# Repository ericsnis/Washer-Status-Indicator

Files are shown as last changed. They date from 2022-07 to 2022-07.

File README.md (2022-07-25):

# Washer Status Indicator
Washing Machine status indicator using ESP32

## Features

- Simple LED indicator for at a glance washing machine and clothes dryer status.
  - Green LED for "OFF / Ready"
  - Red LED for "ON/ In Use"
  - Could be used to indicate status of other things.
- Uses commonly available ESP32 NodeMCU boards or other boards with identical pinout.
  - Not the similarly named **_ESP8266_** NodeMCU boards, which uses different chip and pinout.
  - Tested with [Inland/Microcenter ESP32 board](https://www.microcenter.com/product/613822/inland-esp32-wroom-32d-module).
  - Designs using 1206 SMT or through hole components available.
- Open source hardware
- Software uses [PubSubClient](https://pubsubclient.knolleary.net/) to communicate with MQTT server
  - Uses [OpenHab](https://www.openhab.org/) home automation sever for source of MQTT data.
    - Requires MQTT server such as [Mosquitto](https://mosquitto.org/).
	  - [Basic directions](https://community.openhab.org/t/oh3-mqtt-setup-and-configuration) for Mosquitto and OpenHab
    - Follow directions for configuring [MQTT binding](https://www.openhab.org/addons/bindings/mqtt/).
  - Could be used with other MQTT sources like [Home Assistant](https://www.home-assistant.io/).

## Boards
The schematic folder contains the board and schematic files in Eagle format
- Designs for 1206 SMT LEDs and resistors or through hole components
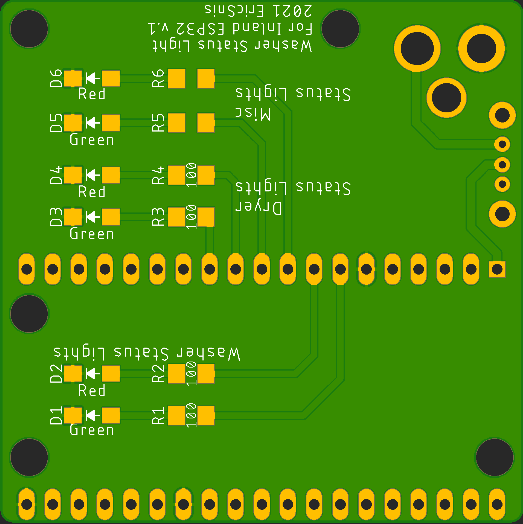
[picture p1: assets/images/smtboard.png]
MQTT washer thing


## Code
The code folder contains the program code to compile and upload to the ESP32
- Use [Platform.io](https://docs.platformio.org/en/latest/integration/ide/vscode.html) installed on [Visual Studio Code](https://code.visualstudio.com/) AKA: VSCode to compile and upload.
- Open the code folder in VSCode then compile, PlatformIO should download any dependencies.

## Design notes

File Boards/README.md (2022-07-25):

# Boards
 The schematic folder contains the board and schematic files in Eagle format

## Files for surface mount (SMT) boards
- _Washer Machine Status Inland ESP32 1206.brd_ - Surface mount board file
- _Washer Machine Status Inland ESP32 1206.sch_ - Surface mount schematic file

## Files for through hole component boards
- _Washer Machine Status Inland ESP32 Through Hole.brd_ - Through hole component board file
- _Washer Machine Status Inland ESP32 Through Hole.sch_ - Through hole component schematic file

**You need _both_ the .brd and .sch files to open the board in Eagle.**

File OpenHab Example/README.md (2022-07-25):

# MQTT Example for OpenHab
- [Basic directions](https://community.openhab.org/t/oh3-mqtt-setup-and-configuration) for Mosquitto and OpenHab
- See [OpenHab Things](https://www.openhab.org/docs/configuration/things.html) and [OpenHab Items](https://www.openhab.org/docs/configuration/items.html) for infomation on setting up items.
- Uses current sensor to monitor power consumed by the machines to determine their states.
  - TP-Link [KP125](https://www.kasasmart.com/us/products/smart-plugs/kasa-smart-plug-slim-energy-monitoring-kp125) or equivalent with energy monitoring.
  - Needs to have an binding available for OpenHab to monitor
    - [List](https://www.openhab.org/addons/) of available OpenHab bindings
	- [TP-Link binding](https://www.openhab.org/addons/bindings/tplinksmarthome/) for OpenHab, includes examples of things and items.
Provided as example with no guarantees express or implied.

## Rule Files
washer.rules
 - Washing machine rules to update status based on wattage used
 - Machine uses less than 2.5 watts when off, wattages exceeding this will be considered "on".
 - Updates WashingMachineStatus to publish update to MQTT topic
dryer.rules
 - Clothes dryer rules to update status based on wattage used
 
## OpenHab Things & Items
 - WashingMachine_Power item is linked to current power used thing on current sensor
 - WashingMachineStatus is item linked to the MQTT thing "washer"
   - Washer thing has channel called WasherStatus
   - WashingMachineStatus is linked to the WasherStatus channel
   - Updates sent to WashingMachineStatus gets published to MQTT topic sensors/washerstatus

**Images of my setup**
### MQTT broker binding
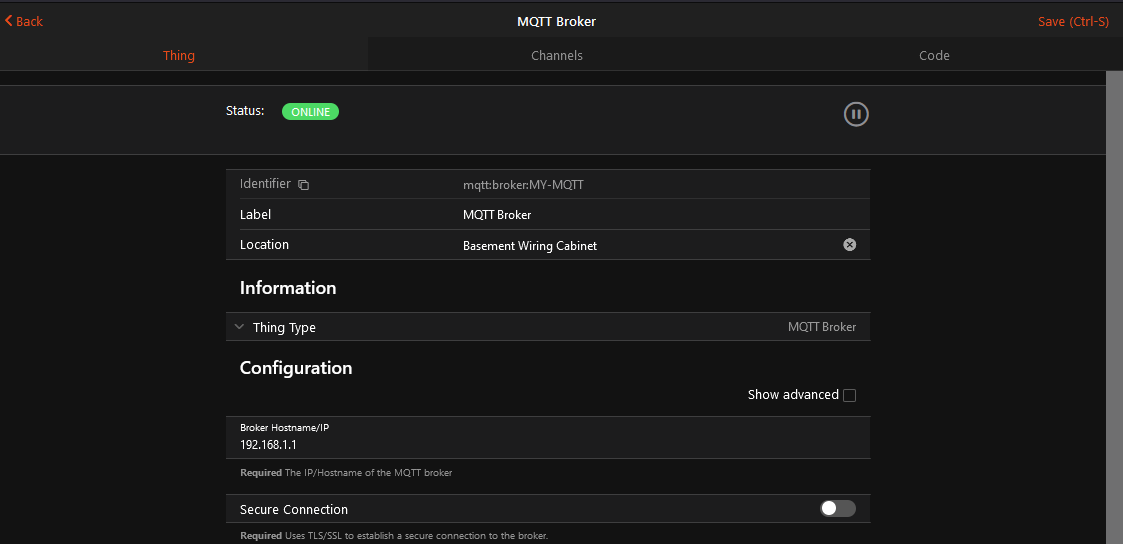
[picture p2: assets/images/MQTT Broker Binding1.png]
MQTT broker binding

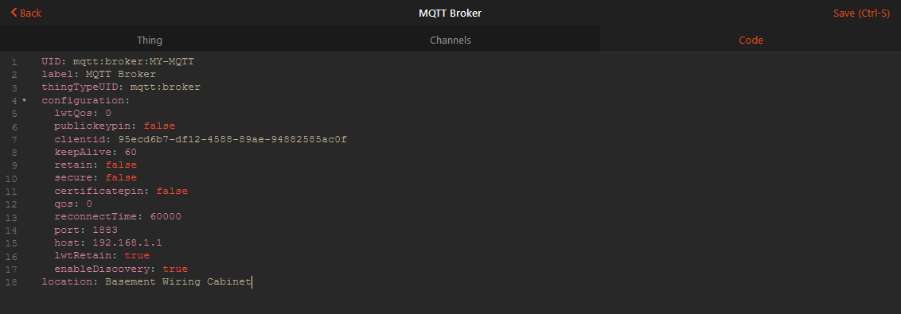
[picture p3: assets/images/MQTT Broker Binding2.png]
MQTT broker binding code


### MQTT washer thing
**Washer thing tab**
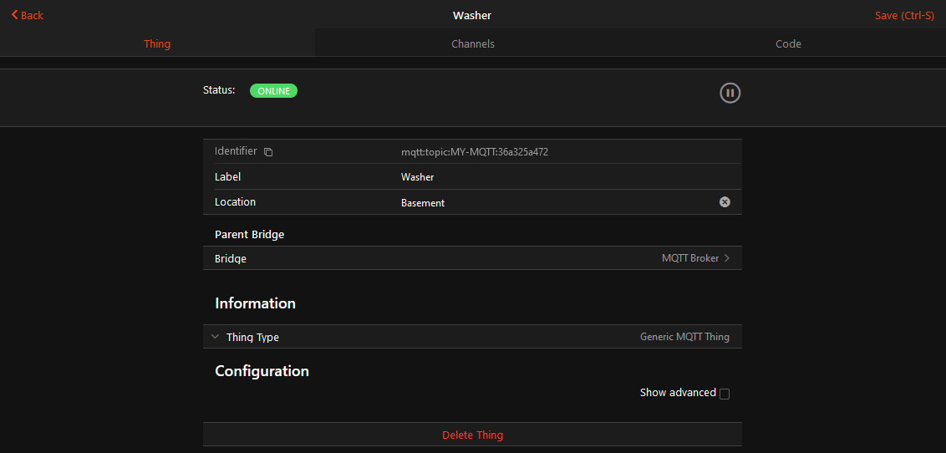
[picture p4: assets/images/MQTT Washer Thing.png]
MQTT washer thing


**Channels tab on washer thing**
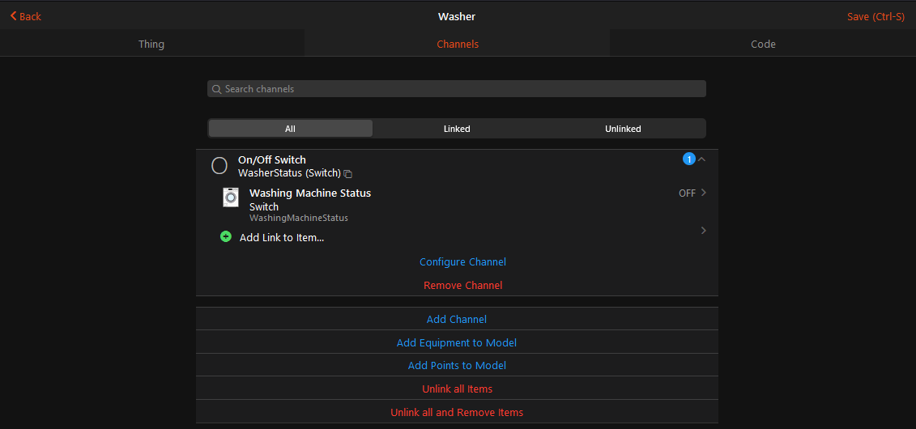
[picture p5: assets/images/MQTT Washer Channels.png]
MQTT washer channels


**Code tab on washer thing**
 - Configures many of the settings on other two tabs.
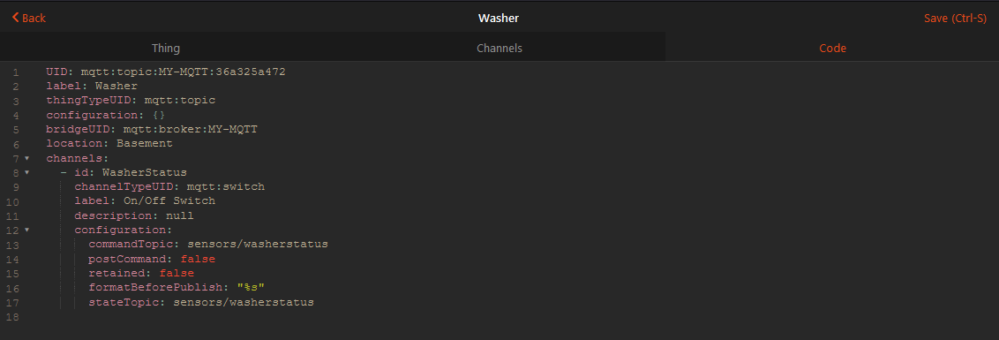
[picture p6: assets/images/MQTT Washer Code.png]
MQTT washer code


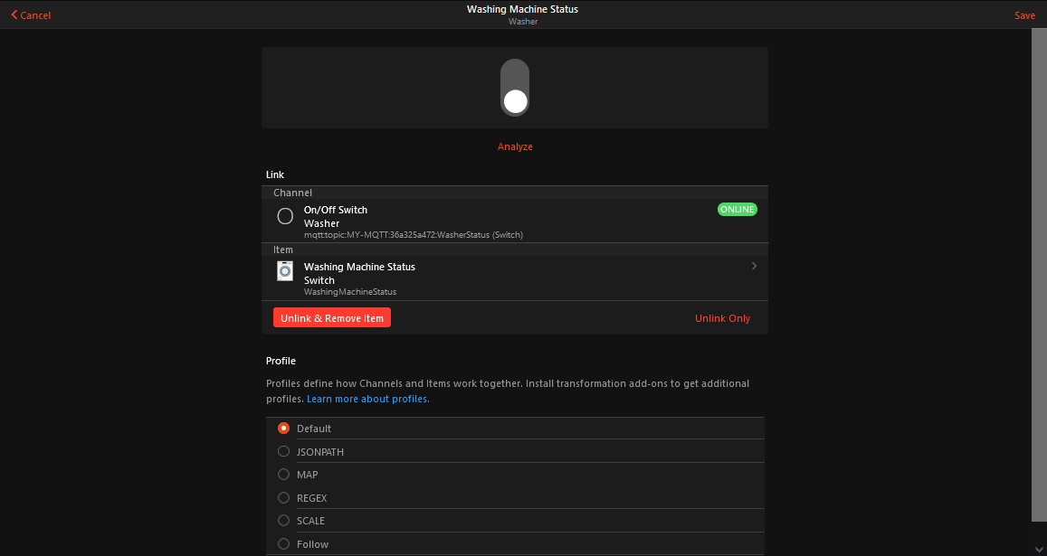
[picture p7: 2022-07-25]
assets/images/Washer Item.png

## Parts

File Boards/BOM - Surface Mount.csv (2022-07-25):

Qty | Item | Manufacturer | Source | Part # | Website
1 | 2.1mm DC barrel jack | CUI | Adafruit | 373 | https://www.adafruit.com/product/373
6 | 100 Ohm Resistor 1206 | Stackpole | DigiKey | RNCP1206FTD100R | https://www.digikey.com/en/products/detail/stackpole-electronics-inc/RNCP1206FTD100R/2240316
3 | Green LED 1206 | Inolux | DigiKey | IN-S126ATG | https://www.digikey.com/en/products/detail/inolux/IN-S126ATG/7604905
3 | Red LED 1206 | Inolux | DigiKey | IN-S126ATR | https://www.digikey.com/en/products/detail/inolux/IN-S126ATR/7604906
0 | Amber LED 1206 | Inolux | DigiKey | IN-S126ATA | https://www.digikey.com/en/products/detail/inolux/IN-S126ATA/7604903
1 | Slide Switch SPDT Through Hole | E-Switch | DigiKey | EG1213 | https://www.digikey.com/en/products/detail/e-switch/EG1213/101735
1 | Inland ESP32-WROOM-32D Module | Inland | Microcenter | KS0413 | https://www.microcenter.com/product/613822/inland-esp32-wroom-32d-module

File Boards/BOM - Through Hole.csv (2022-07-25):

Qty | Item | Manufacturer | Source | Part # | Website
1 | 2.1mm DC barrel jack | CUI | Adafruit | 373 | https://www.adafruit.com/product/373
6 | 100 Ohm Resistor 1/4 Watt Axial | Stackpole | DigiKey | CF14JT100R | https://www.digikey.com/en/products/detail/stackpole-electronics-inc/CF14JT100R/1741261
3 | Green LED 3mm | SunLED | DigiKey | XLVG65D | https://www.digikey.com/en/products/detail/sunled/XLVG65D/13559320
3 | Red LED 3mm | SunLED | DigiKey | XLMDK65D | https://www.digikey.com/en/products/detail/sunled/XLMDK65D/13559277
0 | Yellow LED 3mm | SunLED | DigiKey | XLMYK65D | https://www.digikey.com/en/products/detail/sunled/XLMYK65D/13559343
1 | Slide Switch SPDT Through Hole | E-Switch | DigiKey | EG1213 | https://www.digikey.com/en/products/detail/e-switch/EG1213/101735
1 | Inland ESP32-WROOM-32D Module | Inland | Microcenter | KS0413 | https://www.microcenter.com/product/613822/inland-esp32-wroom-32d-module

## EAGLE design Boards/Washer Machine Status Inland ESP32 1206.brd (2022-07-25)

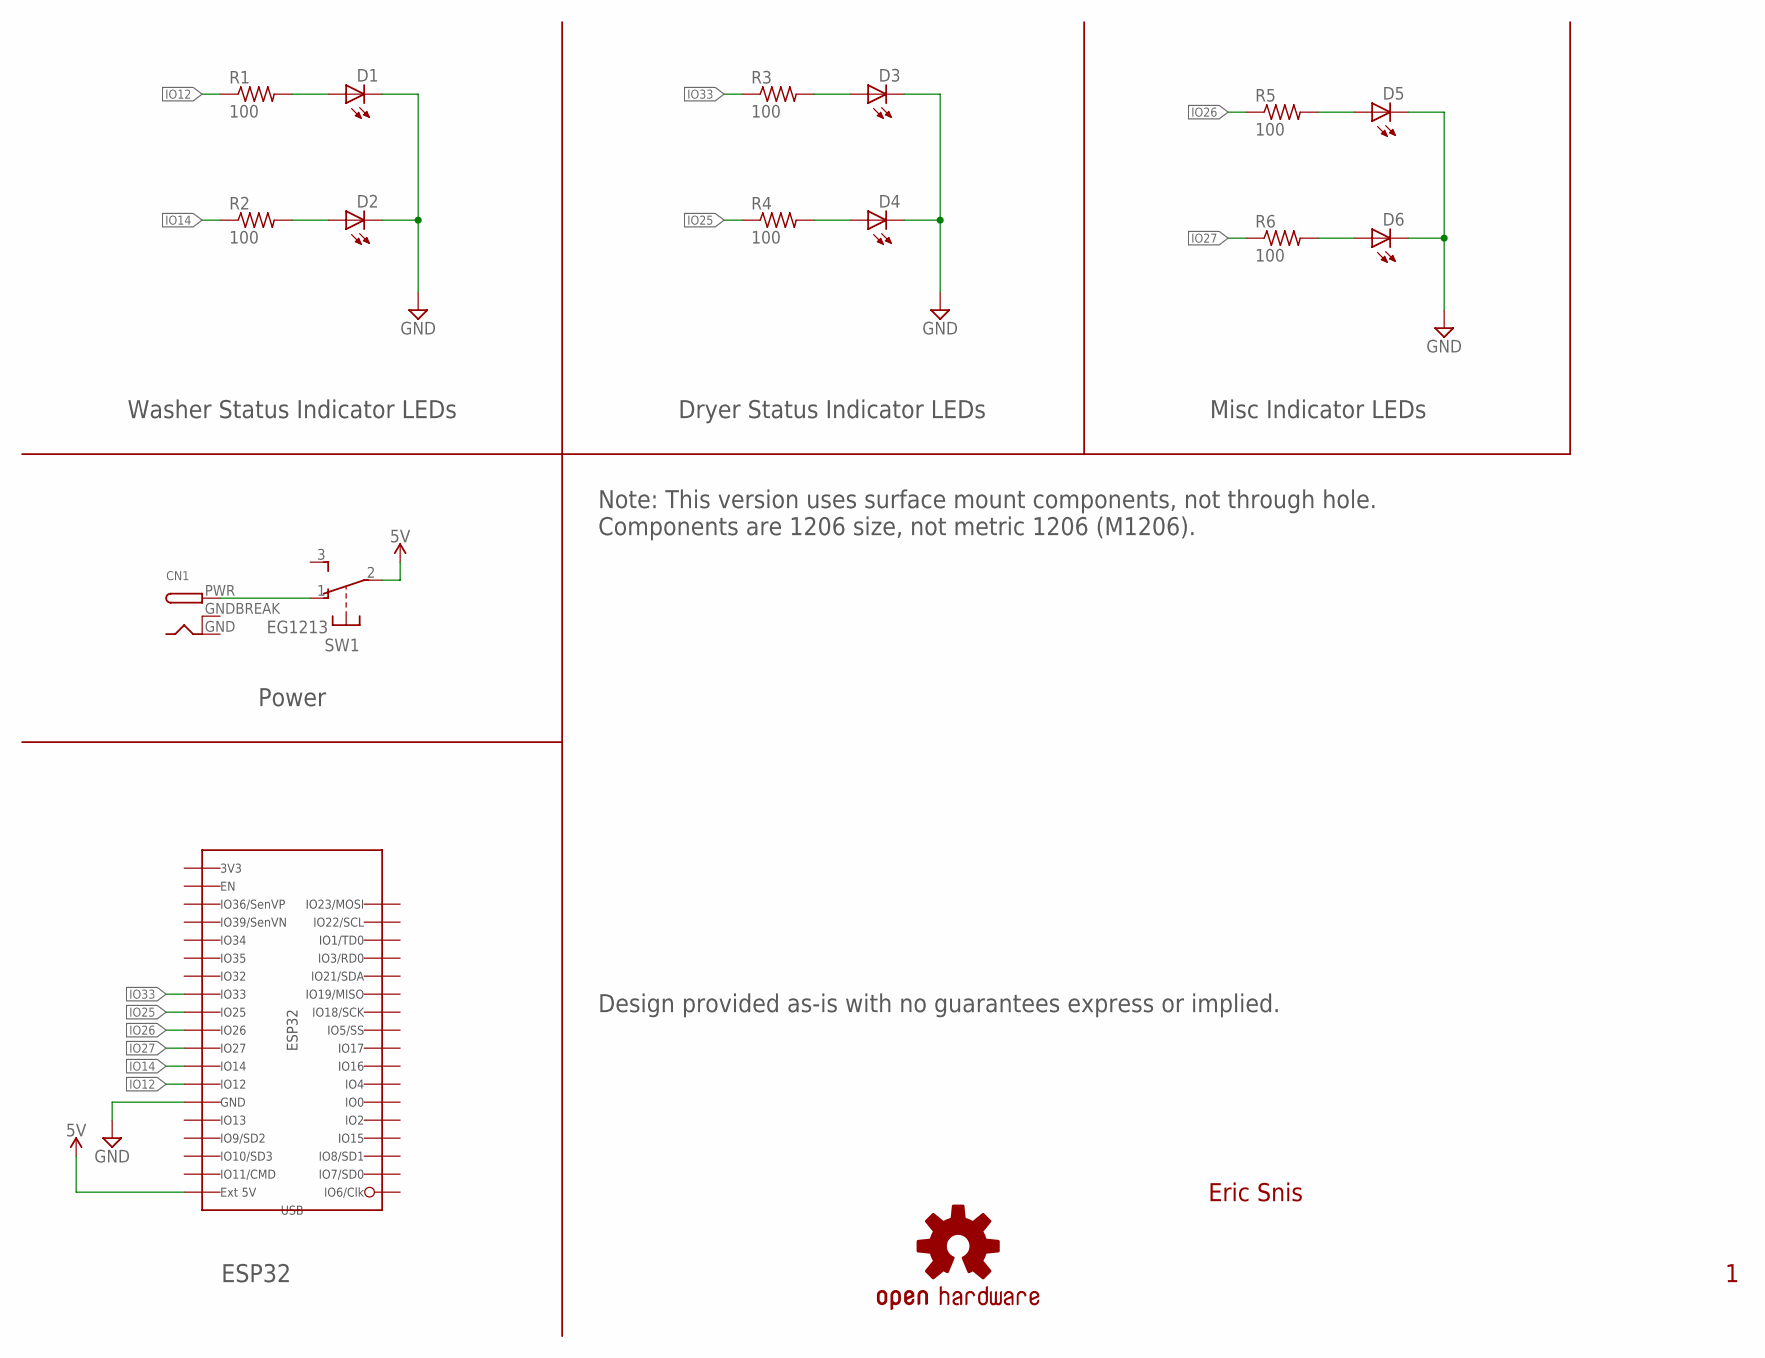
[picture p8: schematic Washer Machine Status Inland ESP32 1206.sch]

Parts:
CN1: DCBARRELPTH; DCJACK_2MM_PTH
D1, D3, D5: Green; CHIPLED_1206_LONG
D2, D4, D6: Red; CHIPLED_1206_LONG
LOGO2: OSHW-LOGOMINI; OSHW-LOGO-MINI
R1, R2, R3, R4, R5, R6: 100; R1206
SW: EG1213
U$3: ESP32-INLAND; ESP32_INLAND

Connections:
3V3: U$3.3V3
5V: SW.2, U$3.5V (EXT_5V)
GND: CN1.GND, D1.C, D2.C, D3.C, D4.C, D5.C, D6.C, U$3.GND (GND1), U$3.GND1, U$3.GND2 (GND1)
GNDBREAK: CN1.GNDBREAK
IO12: R1.1, U$3.IO12
IO14: R2.1, U$3.IO14
IO25: R4.1, U$3.IO25
IO26: R5.1, U$3.IO26
IO27: R6.1, U$3.IO27
IO33: R3.1, U$3.IO33
unnamed: CN1.PWR, SW.1 (O)
unnamed: D5.A, R5.2
unnamed: D1.A, R1.2
unnamed: D2.A, R2.2
unnamed: D3.A, R3.2
unnamed: D4.A, R4.2
unnamed: D6.A, R6.2

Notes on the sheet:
Washer Status Indicator LEDs
Power
ESP32
Dryer Status Indicator LEDs
Misc Indicator LEDs
Note: This version uses surface mount components, not through hole. Components are 1206 size, not metric 1206 (M1206).
Design provided as-is with no guarantees express or implied.

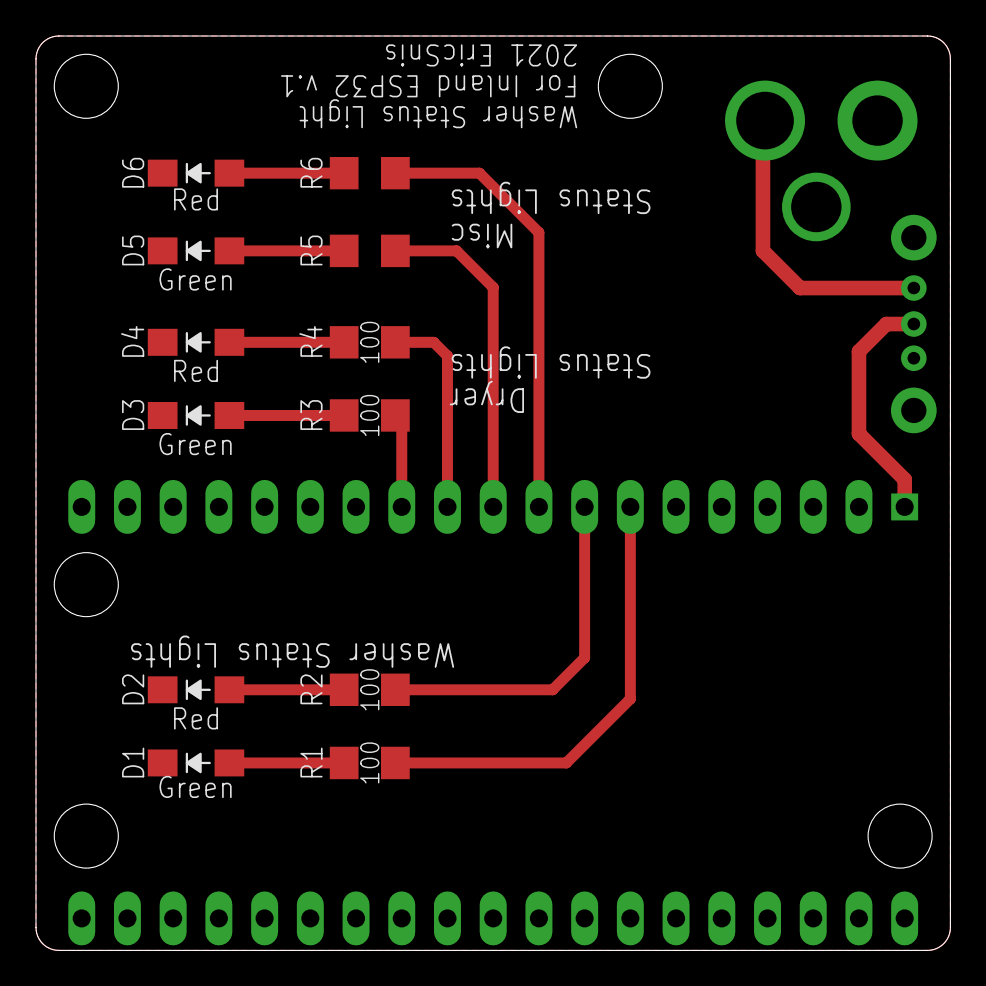
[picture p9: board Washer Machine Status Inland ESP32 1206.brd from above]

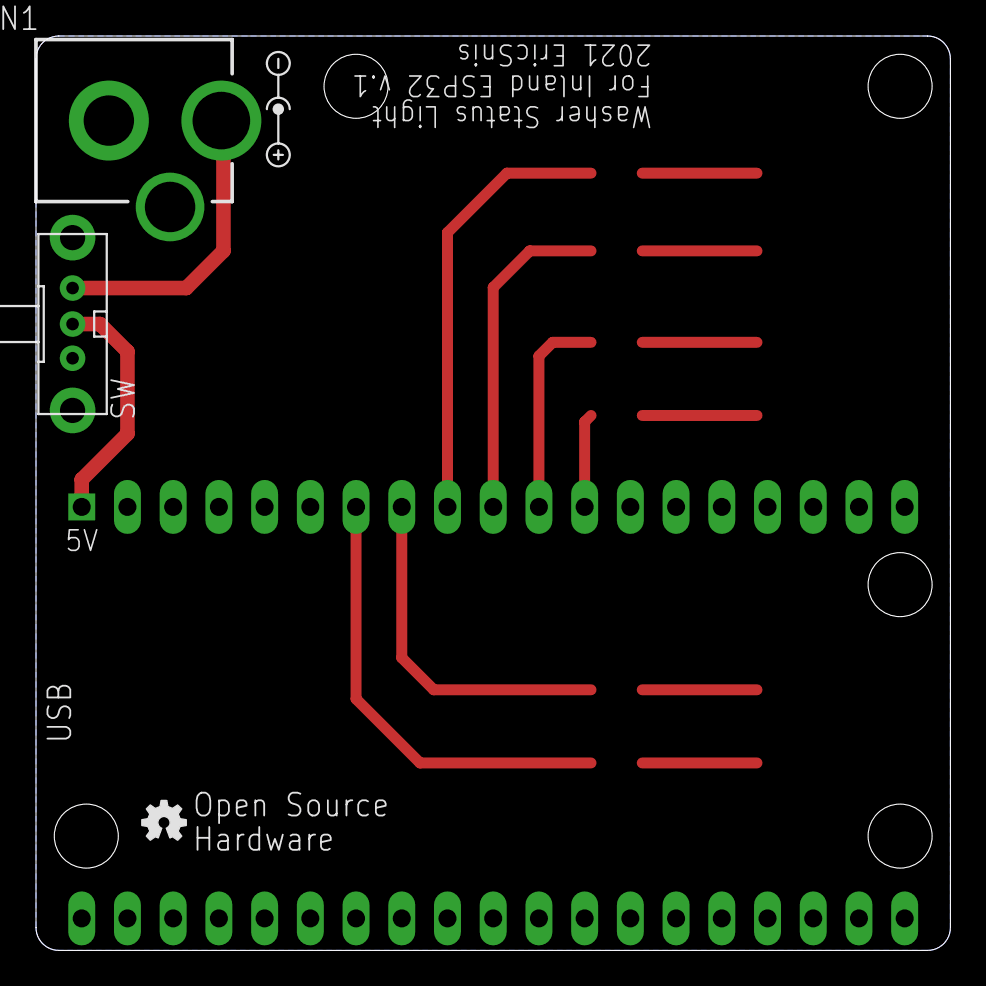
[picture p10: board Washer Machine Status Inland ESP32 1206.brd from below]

Board: 2 copper layers, 50.8 x 50.8 mm, 17 parts (5 on the bottom side), 15 nets.

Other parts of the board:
U$1: CENTER-POS-SMALL

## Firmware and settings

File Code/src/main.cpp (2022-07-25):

/*
  Washing machine status for ESP32
  2021 EricSnis
  
  It connects to an MQTT server then:
  - checks washing machine status (topic sensors/washerstatus)
  - checks clothes dryer status (topic sensors/dryerstatus)
  - checks miscellaneous status (topic sensors/misc)
  - Indicates OFF with green LED (Ready)
  - Indicates ON with red LED (In Use)
  MQTT Topic can be changed to suit by changing TOPIC1, TOPIC2 & TOPIC3
  
  Assumes use of ESP32 based NodeMCU board, not similarly named ESP8266 NodeMCU.
  - Can be changed to other boards if pinout is changed
  - LED board would need to be changed if another board is used
  
  Code released under MIT License
*/

#include <WiFi.h>
#include <PubSubClient.h>

const char *ssid = "YourWiFiName";           // name of your WiFi network
const char *password = "YourWiFiPassword"; // password of the WiFi network

int WasherOffLEDPin = 12; // Washer OFF status light (Green)
int WasherOnLEDPin = 14;  // Washer ON status light (Red)
int DryerOffLEDPin = 33;  // Dryer OFF status light (Green)
int DryerOnLEDPin = 25;   // Dryer ON status light (Red)
int Misc1LEDPin = 26;  // Misc indicator light 1 (Green)
int Misc2LEDPin = 27;  // Misc indicator light 2 (Red)

const char *ID = "ESP32-WasherStatus";      // Hostname of our device, must be unique
const char *TOPIC1 = "sensors/washerstatus"; // MQTT topic for washing machine status
const char *TOPIC2 = "sensors/dryerstatus"; // MQTT topic for clothes dryer status indication
const char *TOPIC3 = "sensors/misc"; // MQTT topic for misc status indication

IPAddress broker(192, 168, 1, 1); // IP address of your MQTT on OpenHab server
WiFiClient wclient;

PubSubClient client(wclient); // Setup MQTT client

// Handle incomming messages from the broker
void callback(char *topic, byte *payload, unsigned int length)
{
  String response;

  for (int i = 0; i < length; i++)
  {
    response += (char)payload[i];
  }
  Serial.print("Message arrived [");
  Serial.print(topic);
  Serial.print("] ");
  Serial.println(response);

  if (strcmp(topic, TOPIC1) == 0)
  {
    if (response == "ON")
    {
      Serial.print("MQTT says washer is ON");
      digitalWrite(WasherOnLEDPin, HIGH); // Turn on washer ON (Red) LED
      digitalWrite(WasherOffLEDPin, LOW); // Turn off washer OFF (Green) LED
    }
    else if (response == "OFF")
    {
      Serial.print("MQTT says washer is OFF");
      digitalWrite(WasherOnLEDPin, LOW);   // Turn off washer ON (Red) LED
      digitalWrite(WasherOffLEDPin, HIGH); // Turn on washer OFF (Green) LED
    }
  }
  if (strcmp(topic, TOPIC2) == 0)
  {
    if (response == "ON")
    {
      Serial.print("MQTT says dryer is ON");
      digitalWrite(DryerOnLEDPin, HIGH); // Turn on dryer ON (Red) LED
      digitalWrite(DryerOffLEDPin, LOW); // Turn off dryer OFF (Green) LED
    }
    else if (response == "OFF")
    {
      Serial.print("MQTT says dryer is OFF");
      digitalWrite(DryerOnLEDPin, LOW);   // Turn off dryer ON (Red) LED
      digitalWrite(DryerOffLEDPin, HIGH); // Turn on dryer OFF (Green) LED
    }
  }
  if (strcmp(topic, TOPIC3) == 0)
  {
    if (response == "ON")
    {
      Serial.print("MQTT says misc is ON");
      digitalWrite(Misc1LEDPin, HIGH); // Turn on Misc 1 (Green) LED
      digitalWrite(Misc2LEDPin, LOW); // Turn off Misc 2 (Red) LED
    }
    else if (response == "OFF")
    {
      Serial.print("MQTT says misc is OFF");
      digitalWrite(Misc1LEDPin, LOW);   // Turn off Misc 1 (Green) LED
      digitalWrite(Misc2LEDPin, HIGH); // Turn on Misc 2 (Red) LED
    }
  }
}

// Connect to WiFi network
void setup_wifi()
{
  Serial.print("\nConnecting to ");
  Serial.println(ssid);

  WiFi.begin(ssid, password); // Connect to network

  while (WiFi.status() != WL_CONNECTED)
  { // Wait for connection
    delay(500);
    Serial.print(".");
  }

  Serial.println();
  Serial.println("WiFi connected");
  Serial.print("IP address: ");
  Serial.println(WiFi.localIP());
}

void reconnect()
{ // Reconnect to client
  // Loop until we're reconnected
  while (!client.connected())
  {
    Serial.print("Attempting MQTT connection...");
    // Attempt to connect
    if (client.connect(ID))
    {
      client.subscribe(TOPIC1);
      client.subscribe(TOPIC2);
      client.subscribe(TOPIC3);
      Serial.println("connected");
      Serial.print("Subcribed to: ");
      Serial.println(TOPIC1);
      Serial.println('\n');
      Serial.println(TOPIC2);
      Serial.println('\n');
      Serial.println(TOPIC3);
      Serial.println('\n');
    }
    else
    {
      Serial.println(" try again in 5 seconds"); // Wait 5 seconds before retrying
      delay(5000);
    }
  }
}

void setup()
{
  Serial.begin(9600);               // Start serial communication at 9600 baud
  pinMode(WasherOnLEDPin, OUTPUT);  // Configure Washer On pin as an output
  pinMode(WasherOffLEDPin, OUTPUT); // Configure Washer Off pin as an output
  pinMode(DryerOnLEDPin, OUTPUT); // Configure Dryer On pin as an output
  pinMode(DryerOffLEDPin, OUTPUT); // Configure Dryer Off pin as an output
  pinMode(Misc1LEDPin, OUTPUT); // Configure Misc indicator 1 pin as an output
  pinMode(Misc2LEDPin, OUTPUT); // Configure Misc indicator 2 pin as an output

  Serial.print("Testing LED bulbs");
  digitalWrite(WasherOnLEDPin, HIGH); // Turn on washer OFF (Green) LED
  delay(250);
  digitalWrite(WasherOnLEDPin, LOW); // Turn off washer OFF (Green) LED
  delay(250);
  digitalWrite(WasherOffLEDPin, HIGH); // Turn on washer ON (Red) LED
  delay(250);
  digitalWrite(WasherOffLEDPin, LOW); // Turn off washer ON (Red) LED
  delay(250);
  digitalWrite(DryerOnLEDPin, HIGH); // Turn on dryer OFF (Green) LED
  delay(250);
  digitalWrite(DryerOnLEDPin, LOW); // Turn off dryer OFF (Green) LED
  delay(250);
  digitalWrite(DryerOffLEDPin, HIGH); // Turn on dryer ON (Red) LED
  delay(250);
  digitalWrite(DryerOffLEDPin, LOW); // Turn off dryer ON (Red) LED
  delay(250);
  digitalWrite(Misc1LEDPin, HIGH); // Turn ON Misc LED 1 (Green) LED
  delay(250);
  digitalWrite(Misc1LEDPin, LOW); // Turn OFF Misc LED 1 (Green) LED
  delay(250);
  digitalWrite(Misc2LEDPin, HIGH); // Turn ON Misc LED 2 (Red) LED
  delay(250);
  digitalWrite(Misc2LEDPin, LOW); // Turn OFF Misc LED 2 (Red) LED
  delay(100);

  setup_wifi(); // Connect to network
  client.setServer(broker, 1883);
  client.setCallback(callback); // Initialize the callback routine
}

void loop()
{
  if (!client.connected()) // Reconnect if connection is lost
  {
    reconnect();
  }
  client.loop();
}

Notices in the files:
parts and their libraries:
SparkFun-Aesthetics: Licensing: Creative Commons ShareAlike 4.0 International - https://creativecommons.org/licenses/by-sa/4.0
